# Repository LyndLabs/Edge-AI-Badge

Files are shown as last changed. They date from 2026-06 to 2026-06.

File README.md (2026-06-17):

# Edge AI Foundation Badge

  

The Edge AI Badge lets you plug-and-play with the latest vendor hardware at conference workshops and wirelessly connect with other attendees! Use the badge to explore the Edge AI curriculum, plug into sensors, and start building apps.

- 📄 [Read the docs →](https://lyndlabs.github.io/edge-ai-badge-docs)
- 💻 [Download or contribute to firmware](https://github.com/lyndlabs/edge-ai-badge-firmware).

## Hardware 
The badge is a modular PCB that allows you to customize your own face & backplates - the hardware platform is consistent at future conferences and makes it easy for attendees to design their own add-ons, or vendors that want to contribute hardware. 

It's built around the ESP32-S3, selected for its cryptographic core + secure boot, communication protocols (WiFi, BLE, ESP-NOW), infrared hardware, native USB, and ubiquitous support.

---

## Contents
- **assets**: logos, renders, global design assets
    - *find local assets under subfolders*
- **pcb**: KiCAD design files for `main`, `face`, `back`
- **fab**: production-ready pcb + laser files

## Versions & Notes
Versions bumped per batch release, revisions tracked for minor design changes per board - `main`, `face`, `back` tracked separately.

### v0 - 26/06/08
- Main boards + backplate only - released in green HASL
- Wrong SMD standoff drilling size + CPL in production batch - used regular standoffs
- CPL + BOM discrepancy, released for visibility but pls do not order

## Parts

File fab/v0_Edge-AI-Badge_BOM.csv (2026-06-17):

Reference | Value | DNP | Footprint | Datasheet | LCSC
C1,C40,C41 | 22uF |  | Capacitor_SMD:C_0402_1005Metric |  | C3845593
C2,C12,C18,C37 | 100nF |  | Capacitor_SMD:C_0402_1005Metric |  | C1525
C3,C4,C6,C21 | 0.1uF |  | Capacitor_SMD:C_0402_1005Metric |  | C1525
C5,C17,C19,C24,C25,C33 | 1uF |  | Capacitor_SMD:C_0402_1005Metric |  | C14445,C3845593
C9,C10 | 4.7uF |  | Capacitor_SMD:C_0402_1005Metric |  | C315248
C13,C27 | 10uF |  | Capacitor_SMD:C_0402_1005Metric |  | C315248
C38 | 22pF |  | Capacitor_SMD:C_0402_1005Metric |  | C76960
D1,D3,D4,D6 | D_Schottky |  | Diode_SMD:D_SOD-523 |  | C917006
D10 | PRTR5V0U2X |  | Package_TO_SOT_SMD:SOT-143 | https://assets.nexperia.com/documents/data-sheet/PRTR5V0U2X.pdf | C5180302
D14,D15 | VSMY14940 |  | Temporal:vsmy14940 |  | C511069
H1,H2,H3,H4 | M2 x 1.5mm |  |  |  | C5301775
H5,H6,H7,H8 | M2x6mm |  |  |  | C5301797
J1 | USB C 2.0 |  | Connector_USB:USB_C_Receptacle_Palconn_UTC16-G | https://www.usb.org/sites/default/files/documents/usb_type-c.zip | C2765186
J3 | JST PH |  | Connector_JST:JST_PH_S2B-PH-SM4-TB_1x02-1MP_P2.00mm_Horizontal |  | C295747
J5,J6 | SM04B
L5 | 2.2uh |  | Inductor_SMD:L_Coilcraft_LPS3010 | https://www.lcsc.com/datasheet/lcsc_datasheet_2410121211_YJYCOIN-YHNR4020-2R2M_C2926400.pdf | C2926400
LED1,LED2,LED3,LED4,LED5,LED6,LED7,LED8,LED9,LED10,LED11,LED12 | APA102-2020 |  | LED_SMD:LED-APA102-2020 | http://www.led-color.com/upload/201604/APA102-2020%20SMD%20LED.pdf
M1 | Z3OC1T8219731
Q1,Q3 | DMN2058U |  | Package_TO_SOT_SMD:SOT-23 | http://www.diodes.com/assets/Datasheets/DMN2058U.pdf | C461001
Q2 | MMBT3904 |  | Package_TO_SOT_SMD:SOT-23 | https://www.onsemi.com/pdf/datasheet/pzt3904-d.pdf | C916374
Q4 | BSS138 |  | Package_TO_SOT_SMD:SOT-23 | https://www.onsemi.com/pub/Collateral/BSS138-D.PDF
R1,R2,R3,R4,R5,R12 | 0 |  | Resistor_SMD:R_0201_0603Metric |  | C106228
R6,R16,R18,R21,R26,R28,R29,R30,R31,R32,R38,R45 | 10K |  | Resistor_SMD:R_0402_1005Metric |  | C25767,C60490
R7,R8 | 4.7K |  | Resistor_SMD:R_0402_1005Metric |  | C105871
R9,R10 | 5.1K |  | Resistor_SMD:R_0402_1005Metric |  | C25905
R11,R15,R24 | 150K |  | Resistor_SMD:R_0402_1005Metric |  | C93947
R14 | 680K |  | Resistor_SMD:R_0402_1005Metric |  | C163456
R19,R20 | 1.8K |  | Resistor_SMD:R_0402_1005Metric |  | C203083
R22 | 47K |  | Resistor_SMD:R_0402_1005Metric |  | C163456
R23,R25 | 100K |  | Resistor_SMD:R_0402_1005Metric |  | C60491
R27 | 330 |  | Resistor_SMD:R_0402_1005Metric |  | C112291
R36,R37,R41 | 24 |  | Resistor_SMD:R_0402_1005Metric |  | C270625
R39 | 150 |  | Resistor_SMD:R_0402_1005Metric |  | C138054
R40 | 10 |  | Resistor_SMD:R_0402_1005Metric |  | C138066
SW1 | Reset |  |  |  | C2762971
SW1, SW4,SW5,SW6,SW7,SW8,SW9,SW10,SW11,SW12 | SW_Push |  |  |  | C2762971
U2 | BQ24079RGT |  | Package_DFN_QFN:VQFN-16-1EP_3x3mm_P0.5mm_EP1.6x1.6mm | http://www.ti.com/lit/ds/symlink/bq24079.pdf | C2876751
U3 | ESP32-S3-WROOM-1 |  | RF_Module:ESP32-S3-WROOM-1 | https://www.espressif.com/sites/default/files/documentation/esp32-s3-wroom-1_wroom-1u_datasheet_en.pdf | C2913202
U4 | ST LIS2DH12TR |  | Package_LGA:LGA-12_2x2mm_P0.5mm | https://www.st.com/resource/en/datasheet/lis2DE12.pdf | C110926
U8 | TSOP75338 |  | LyndLabs-Module:TSOP753 |  | C499550
U10 | SY8089 |  | Package_TO_SOT_SMD:SOT-23-5 | https://lcsc.com/product-detail/DC-DC-Converters_Silergy_SY8088AAC_SY8088AAC_C79313.html | C79313
Y1 | 32.768KHz |  | Crystal:Crystal_SMD_3215-2Pin_3.2x1.5mm |  | C97606

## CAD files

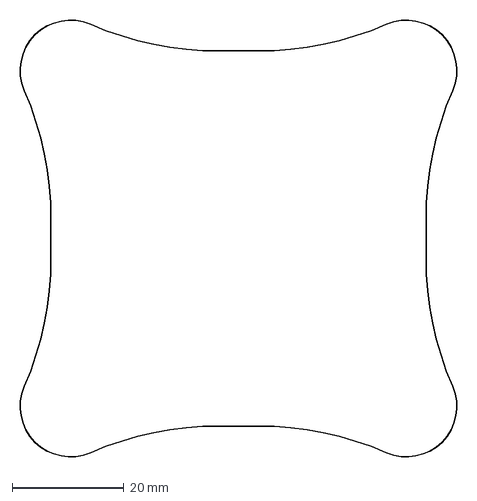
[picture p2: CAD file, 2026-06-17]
assets/outline/v0_Edge-AI-Badge_MAIN-OUTLINE-R1.dxf
79.5 x 79.5 mm

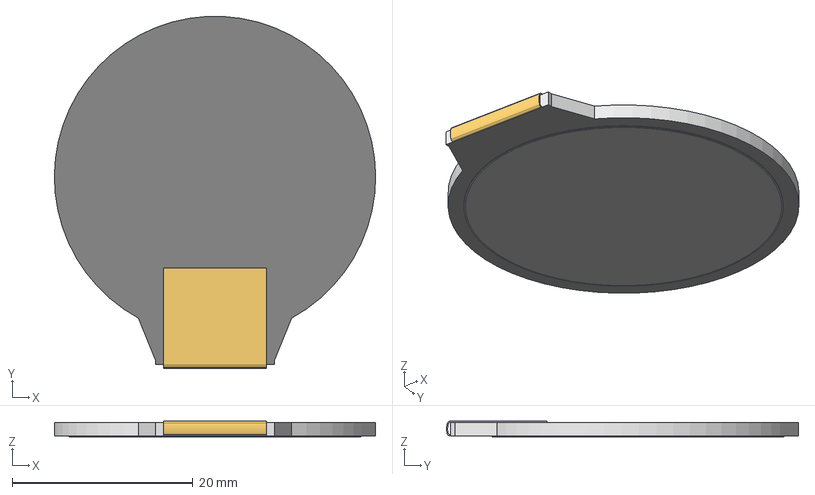
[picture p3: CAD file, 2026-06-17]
assets/models/display.step
35.6 x 39.0 x 1.76 mm
TFT_1.28IN_ROUND_240X240_12P
TFT_1.28IN_ROUND_240X240_12P001
TFT_1.28IN_ROUND_240X240_12P002

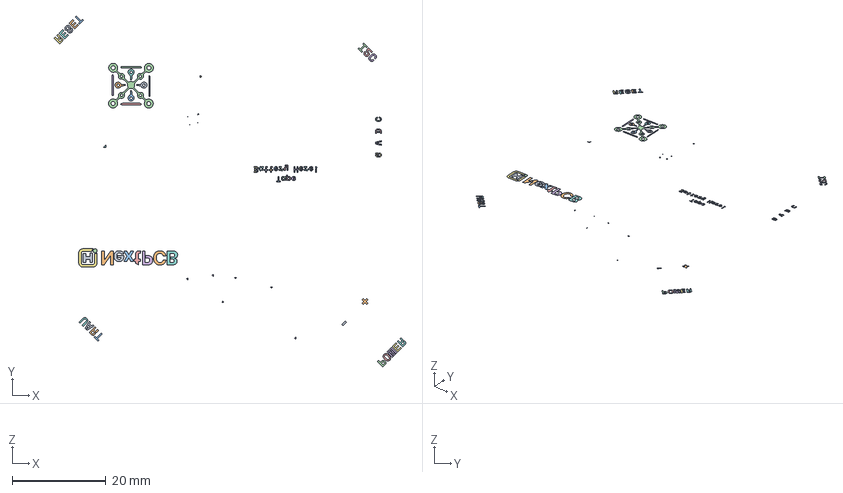
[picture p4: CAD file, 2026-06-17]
assets/outline/V0-Outline.FCStd
75.1 x 75.0 x 0 mm
Path001
Path002
Path003
Path004
Path005
Path006
Path007
Path008
Path009
Path010
Path011
Path012
Path013
Path014
Path015
Path016
Path017
Path018
Path019
Path020
Path021
Path022
Path023
Path024
Path025
Path026
Path027
Path028
Path029
Path030
Path031
Path032
Path033
Path034
Path035
Path036
Path037
Path038
Path039
Path040
Path041
Path042
Path043
Path044
Path045
Path046
Path047
Path048
Path049
Path050
Path068
Path073
Path074
Path075
Path076
Path077
Path078
Path079
Path080
Path081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

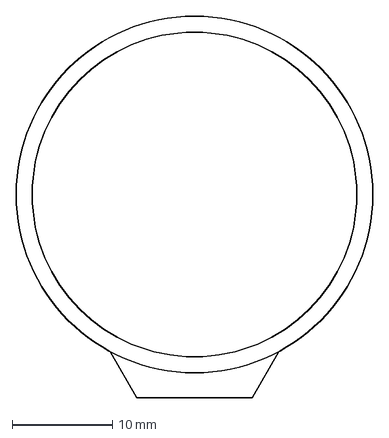
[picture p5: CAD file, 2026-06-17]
assets/Screen-Footprint.dxf
35.6 x 38.1 mm

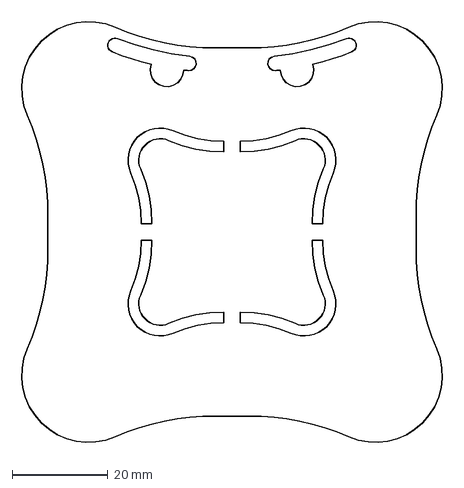
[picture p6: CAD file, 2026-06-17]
assets/outline/v0_Edge-AI-Badge_BACK-OUTLINE-R1.dxf
90.3 x 90.3 mm

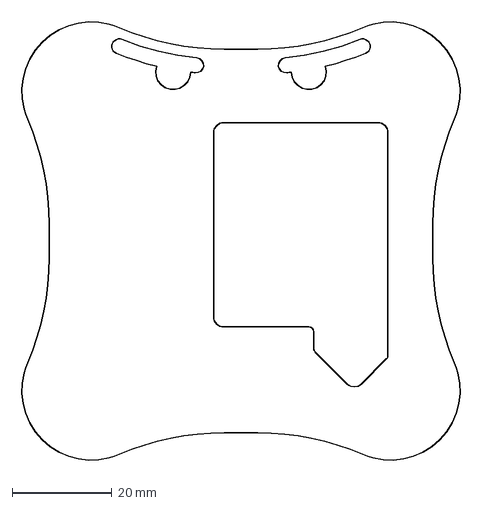
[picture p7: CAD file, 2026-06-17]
assets/outline/v0_Edge-AI-Badge_BACK-OUTLINE-R4.dxf
90.3 x 90.3 mm

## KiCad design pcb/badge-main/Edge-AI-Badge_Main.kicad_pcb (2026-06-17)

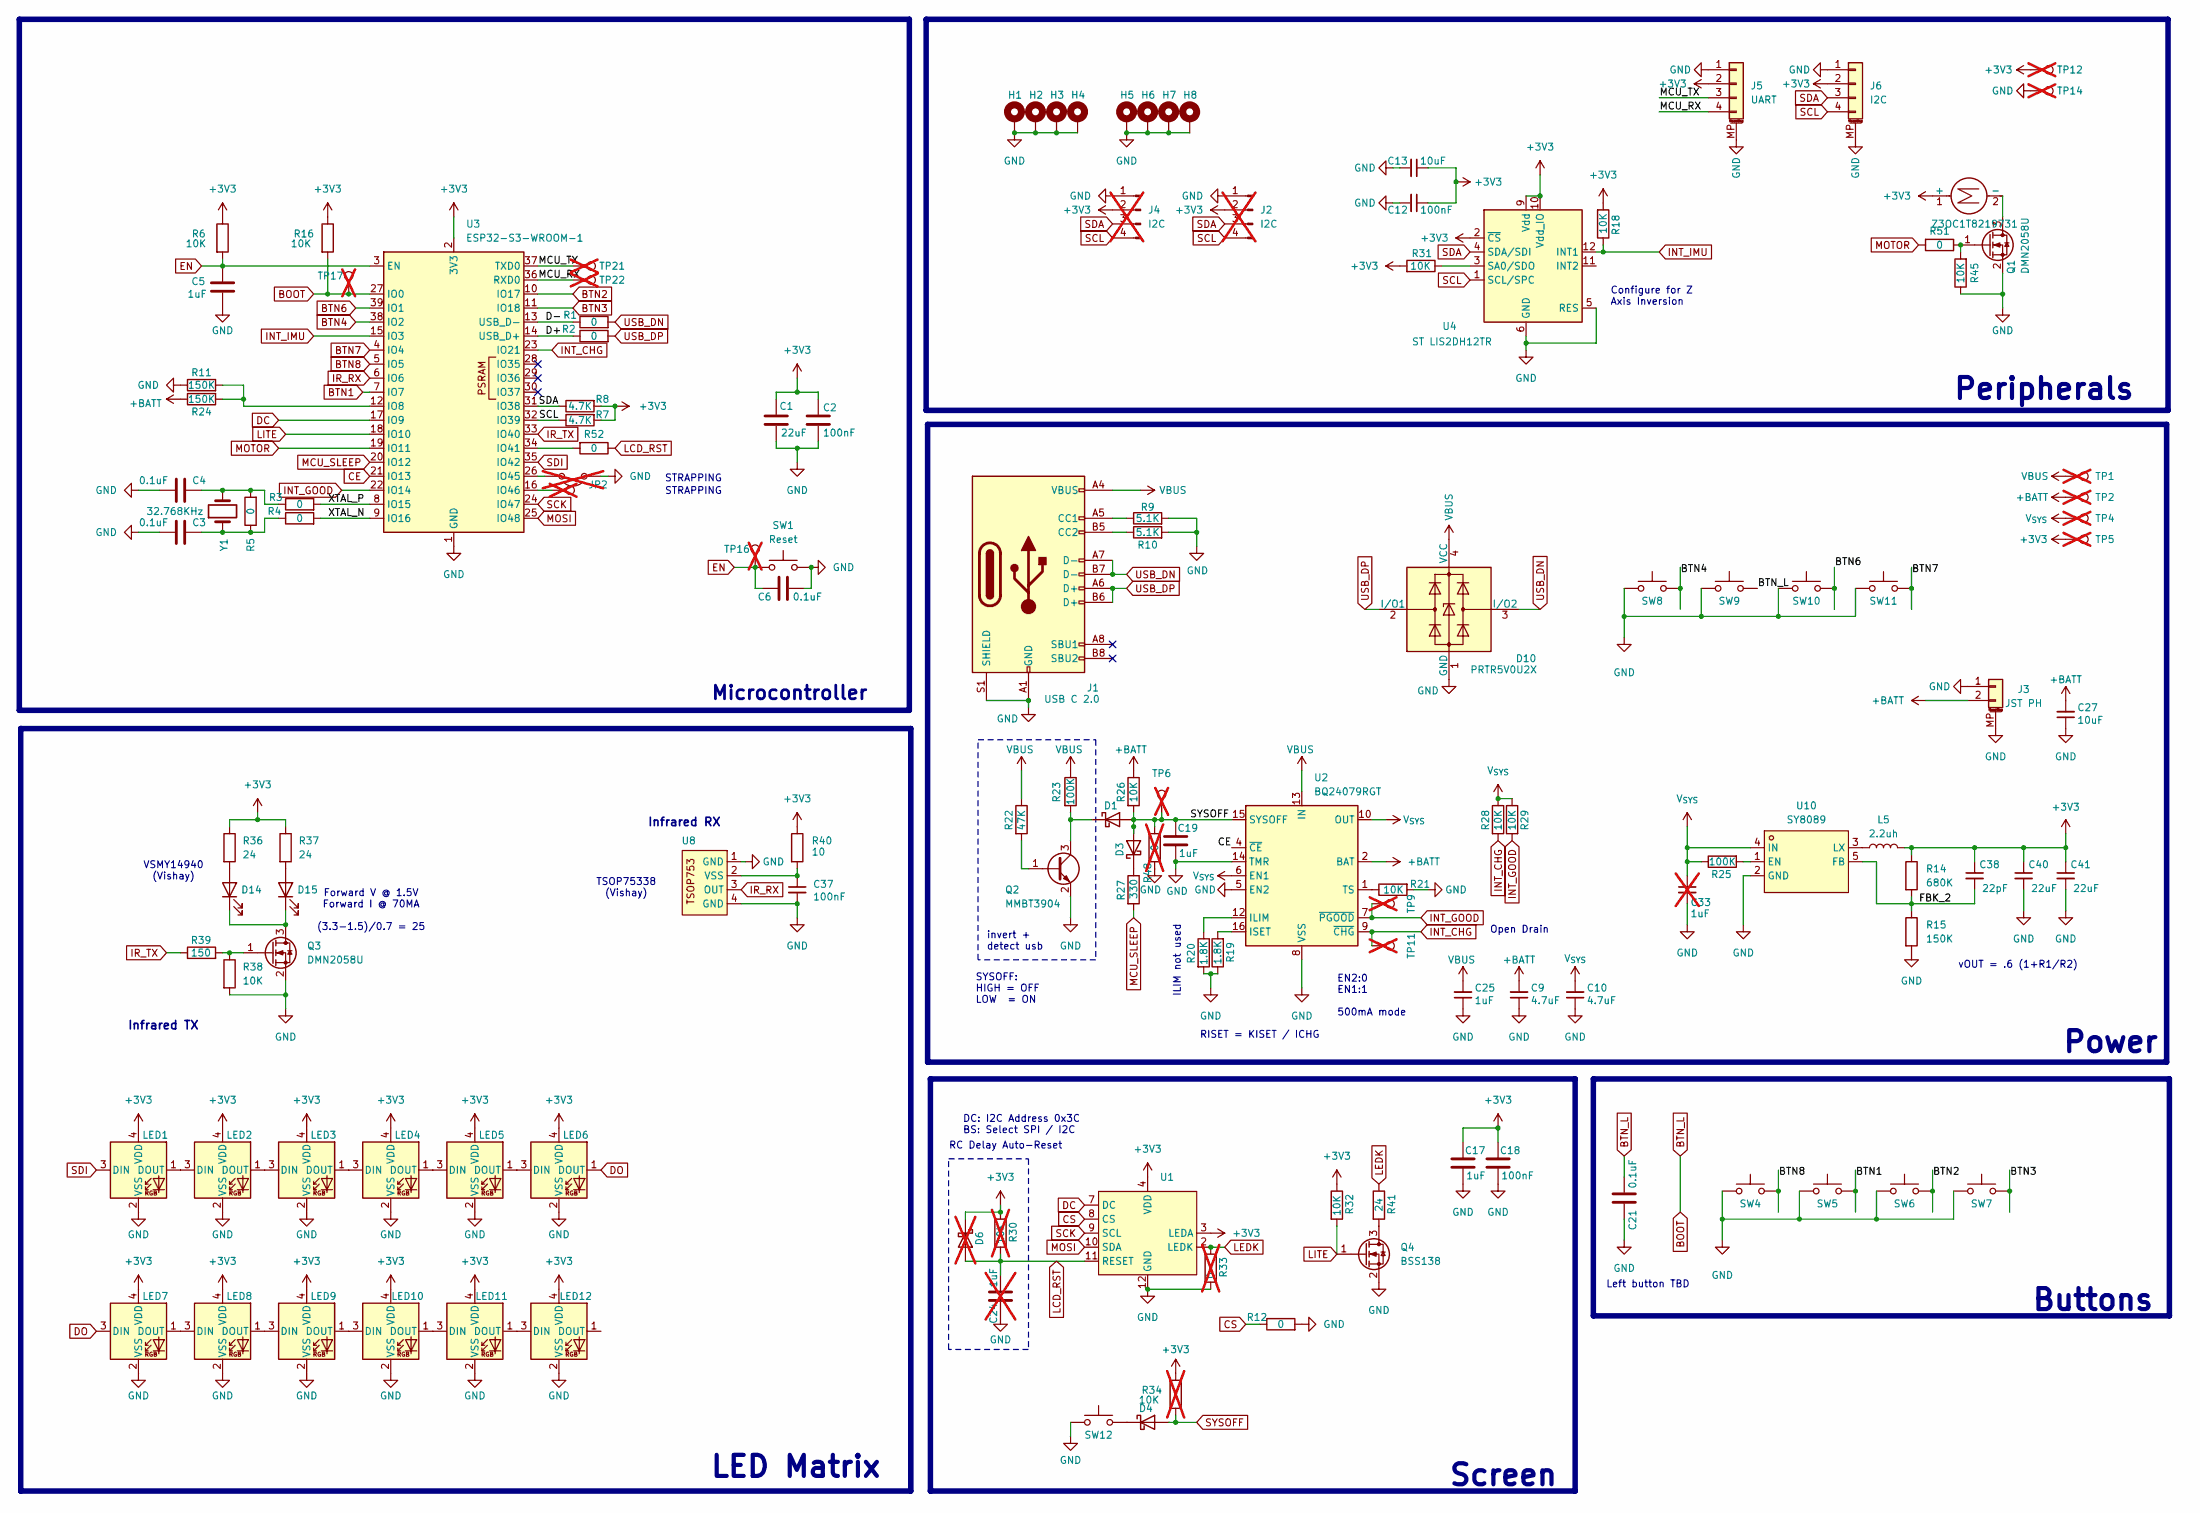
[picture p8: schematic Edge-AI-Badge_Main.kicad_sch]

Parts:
C1, C40, C41: 22uF; C_0402_1005Metric; LCSC C3845593
C2, C12, C18, C37: 100nF; C_0402_1005Metric; LCSC C1525
C3, C4, C6, C21: 0.1uF; C_0402_1005Metric; LCSC C1525
C5, C17, C19, C25: 1uF; C_0402_1005Metric; LCSC C14445
C9, C10: 4.7uF; C_0402_1005Metric; LCSC C315248
C13, C27: 10uF; C_0402_1005Metric; LCSC C315248
C24: 1uF; C_0402_1005Metric; LCSC C14445; not fitted
C33: 1uF; C_0402_1005Metric; LCSC C3845593; not fitted
C38: 22pF; C_0402_1005Metric; LCSC C76960
D1, D3, D4: D_Schottky; D_SOD-523; LCSC C917006
D6: D_Schottky; D_SOD-523; LCSC C917006; not fitted
D10: PRTR5V0U2X; SOT-143; LCSC C5180302
D14, D15: VSMY14940; vsmy14940; LCSC C511069
H1, H2, H3, H4, H5, H6, H7, H8: MountingHole_Pad
J1: USB C 2.0; USB_C_Receptacle_Palconn_UTC16-G; LCSC C2765186
J2, J4: I2C; PinSocket_1x04_P2.54mm_Vertical; not fitted
J3: JST PH; JST_PH_S2B-PH-SM4-TB_1x02-1MP_P2.00mm_Horizontal; LCSC C295747
J5: UART
J6: I2C
JP2: Jumper_2_Open; SolderJumper-2_P1.3mm_Open_RoundedPad1.0x1.5mm; not fitted
L5: 2.2uh; L_Coilcraft_LPS3010; LCSC C2926400
LED1, LED2, LED3, LED4, LED5, LED6, LED7, LED8, LED9, LED10, LED11, LED12: WS2812B-2020; LED_WS2812B-2020_PLCC4_2.0x2.0mm
M1: Z3OC1T8219731
Q1, Q3: DMN2058U; SOT-23; LCSC C461001
Q2: MMBT3904; SOT-23; LCSC C916374
Q4: BSS138; SOT-23
R1, R2, R3, R4, R5, R12: 0; R_0201_0603Metric; LCSC C106228
R6, R16, R18, R21, R31, R32, R38, R45: 10K; R_0402_1005Metric; LCSC C60490
R7, R8: 4.7K; R_0402_1005Metric; LCSC C105871
R9, R10: 5.1K; R_0402_1005Metric; LCSC C25905
R11, R15, R24: 150K; R_0402_1005Metric; LCSC C93947
R14: 680K; R_0402_1005Metric; LCSC C163456
R19, R20: 1.8K; R_0402_1005Metric; LCSC C203083
R22: 47K; R_0402_1005Metric; LCSC C163456
R23, R25: 100K; R_0402_1005Metric; LCSC C60491
R26, R28, R29: 10K; R_0402_1005Metric; LCSC C25767
R27: 330; R_0402_1005Metric; LCSC C112291
R30, R34: 10K; R_0402_1005Metric; LCSC C60490; not fitted
R33: 0; R_0402_1005Metric; LCSC C60490; not fitted
R36, R37, R41: 24; R_0402_1005Metric; LCSC C270625
R39: 150; R_0402_1005Metric; LCSC C138054
R40: 10; R_0402_1005Metric; LCSC C138066
R48: 0; R_0402_1005Metric; LCSC C106228; not fitted
R51, R52: 0; R_0402_1005Metric; LCSC C106228
SW1: Reset; LCSC C231329
SW4, SW5, SW6, SW7, SW8, SW9, SW10, SW11, SW12: SW_Push; LCSC C25168849
TP1, TP2, TP4, TP5, TP6, TP8, TP9, TP11, TP12, TP14, TP16, TP17, TP21, TP22: TestPoint; TestPoint_Pad_D1.0mm; not fitted
U1: GC9A01
U2: BQ24079RGT; VQFN-16-1EP_3x3mm_P0.5mm_EP1.6x1.6mm; LCSC C2876751
U3: ESP32-S3-WROOM-1; LCSC C2913202
U4: ST LIS2DH12TR; LGA-12_2x2mm_P0.5mm; LCSC C110926
U8: TSOP75338; TSOP753; LCSC C499550
U10: SY8089; SOT-23-5; LCSC Part C79313
Y1: 32.768KHz; Crystal_SMD_3215-2Pin_3.2x1.5mm; LCSC C97606

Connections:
+3V3: C1.1, C2.1, C12.1, C13.1, C17.1, C18.1, C38.1, C40.1, C41.1, D6.1 (K), J2.2, J4.2, J5.2, J6.2, L5.2, LED1.4 (VDD), LED2.4 (VDD), LED3.4 (VDD), LED4.4 (VDD), LED5.4 (VDD), LED6.4 (VDD), LED7.4 (VDD), LED8.4 (VDD), LED9.4 (VDD), LED10.4 (VDD), LED11.4 (VDD), LED12.4 (VDD), M1.1 (+), R6.1, R7.2, R8.2, R14.1, R16.1, R18.2, R30.1, R31.2, R32.1, R34.1, R36.1, R37.1, R40.1, TP5.1 (1_1), TP12.1 (1_1), U1.3 (LEDA), U1.4 (VDD), U3.2 (3V3), U4.2 (~CS), U4.9 (Vdd), U4.10 (Vdd_IO)
+BATT: C9.2, C27.2, J3.2, R24.1, R26.1, TP2.1 (1_1), U2.2 (BAT), U2.3 (BAT)
/D+: R2.1, U3.14 (USB_D+)
/D-: R1.1, U3.13 (USB_D-)
/FBK_2: C38.2, R14.2, R15.1, U10.5 (FB)
/MCU_RX: J5.4, TP22.1 (1_1), U3.36 (RXD0)
/MCU_TX: J5.3, TP21.1 (1_1), U3.37 (TXD0)
/XTAL_N: R4.2, U3.9 (IO16)
/XTAL_P: R3.2, U3.8 (IO15)
BOOT: C21.2, R16.2, SW9.2, TP17.1 (1_1), U3.27 (IO0)
BTN1: SW5.2, U3.7 (IO7)
BTN2: SW6.2, U3.10 (IO17)
BTN3: SW7.2, U3.11 (IO18)
BTN4: SW8.2, U3.38 (IO2)
BTN6: SW10.2, U3.39 (IO1)
BTN7: SW11.2, U3.4 (IO4)
BTN8: SW4.2, U3.5 (IO5)
CE: U2.4 (~CE), U3.21 (IO13)
CS: R12.1, U1.8 (CS)
DC: U1.7 (DC), U3.17 (IO9)
DO: LED6.1 (DOUT), LED7.3 (DIN)
EN: C5.1, C6.1, R6.2, SW1.2, TP16.1 (1_1), U3.3 (EN)
GND: C1.2, C2.2, C3.2, C4.2, C5.2, C6.2, C9.1, C10.1, C12.2, C13.2, C17.2, C18.2, C19.2, C21.1, C24.2, C25.1, C27.1, C33.2, C37.2, C40.2, C41.2, D10.1 (GND), H1.1 (1_1), H2.1 (1_1), H3.1 (1_1), H4.1 (1_1), H5.1 (1_1), H6.1 (1_1), H7.1 (1_1), H8.1 (1_1), J1.A1 (GND), J1.A12 (GND), J1.B1 (GND), J1.B12 (GND), J1.S1 (SHIELD), J2.1, J3.1, J3.MP (MountPin), J4.1, J5.1, J5.MP (MountPin), J6.1, J6.MP (MountPin), JP2.2 (B), LED1.2 (VSS), LED2.2 (VSS), LED3.2 (VSS), LED4.2 (VSS), LED5.2 (VSS), LED6.2 (VSS), LED7.2 (VSS), LED8.2 (VSS), LED9.2 (VSS), LED10.2 (VSS), LED11.2 (VSS), LED12.2 (VSS), Q1.2 (S), Q2.2 (E), Q3.2 (S), Q4.2 (S), R9.2, R10.2, R11.1, R12.2, R15.2, R19.1, R20.2, R21.2, R33.2, R38.2, R45.1, R48.1, SW1.1, SW4.1, SW5.1, SW6.1, SW7.1, SW8.1, SW9.1, SW10.1, SW11.1, SW12.1, TP14.1 (1_1), U1.1 (GND), U1.5 (GND), U1.6 (GND), U1.12 (GND), U2.5 (EN2), U2.8 (VSS), U2.14 (TMR), U2.17 (VSS), U3.1 (GND), U3.40 (GND), U3.41 (GND), U4.5 (RES), U4.6 (GND), U4.7 (GND), U4.8 (GND), U8.1 (GND), U8.4 (GND), U10.2 (GND)
INT_CHG: R28.2, TP11.1 (1_1), U2.9 (~CHG), U3.23 (IO21)
INT_GOOD: R29.2, TP9.1 (1_1), U2.7 (~PGOOD), U3.22 (IO14)
INT_IMU: R18.1, U3.15 (IO3), U4.12 (INT1)
IR_RX: U3.6 (IO6), U8.3 (OUT)
IR_TX: R39.1, U3.33 (IO40)
LCD_RST: C24.1, D6.2 (A), R30.2, R52.1, U1.11 (RESET)
LEDK: R33.1, R41.1, U1.2 (LEDK)
LITE: Q4.1 (G), R32.2, U3.18 (IO10)
MCU_SLEEP: R27.2, U3.20 (IO12)
MOSI: U1.10 (SDA), U3.25 (IO48)
MOTOR: R51.2, U3.19 (IO11)
unnamed: C3.1, R4.1, R5.1, Y1.1
unnamed: C4.1, R3.1, R5.2, Y1.2
unnamed: D1.1 (K), Q2.3 (C), R23.2
unnamed: D3.1 (K), R27.1
unnamed: D4.1 (K), SW12.2
unnamed: D14.2 (A), R36.2
unnamed: D14.1 (K), D15.1 (K), Q3.3 (D)
unnamed: D15.2 (A), R37.2
unnamed: J1.A5 (CC1), R9.1
unnamed: J1.B5 (CC2), R10.1
unnamed: JP2.1 (A), U3.26 (IO45)
unnamed: LED1.1 (DOUT), LED2.3 (DIN)
unnamed: LED2.1 (DOUT), LED3.3 (DIN)
unnamed: LED3.1 (DOUT), LED4.3 (DIN)
unnamed: LED4.1 (DOUT), LED5.3 (DIN)
unnamed: LED5.1 (DOUT), LED6.3 (DIN)
unnamed: LED7.1 (DOUT), LED8.3 (DIN)
unnamed: LED8.1 (DOUT), LED9.3 (DIN)
unnamed: LED9.1 (DOUT), LED10.3 (DIN)
unnamed: LED10.1 (DOUT), LED11.3 (DIN)
unnamed: LED11.1 (DOUT), LED12.3 (DIN)
unnamed: M1.2 (-), Q1.3 (D)
unnamed: Q1.1 (G), R45.2, R51.1
unnamed: Q2.1 (B), R22.2
unnamed: Q3.1 (G), R38.1, R39.2
unnamed: Q4.3 (D), R41.2
unnamed: R20.1, U2.12 (ILIM)
unnamed: R19.2, U2.16 (ISET)
unnamed: R21.1, U2.1 (TS)
unnamed: R11.2, R24.2, U3.12 (IO8)
unnamed: R52.2, U3.34 (IO41)
unnamed: TP8.1 (1_1), U3.16 (IO46)
unnamed: R31.1, U4.3 (SA0/SDO)
unnamed: C37.1, R40.2, U8.2 (VSS)
unnamed: R25.2, U10.1 (EN)
unnamed: L5.1, U10.3 (LX)
SCK: U1.9 (SCL), U3.24 (IO47)
SCL: J2.4, J4.4, J6.4, R7.1, U3.32 (IO39), U4.1 (SCL/SPC)
SDA: J2.3, J4.3, J6.3, R8.1, U3.31 (IO38), U4.4 (SDA/SDI)
SDI: LED1.3 (DIN), U3.35 (IO42)
SYSOFF: C19.1, D1.2 (A), D3.2 (A), D4.2 (A), R26.2, R34.2, R48.2, TP6.1 (1_1), U2.15 (SYSOFF)
USB_DN: D10.3 (I/O2), J1.A7 (D-), J1.B7 (D-), R1.2
USB_DP: D10.2 (I/O1), J1.A6 (D+), J1.B6 (D+), R2.2
VBUS: C25.2, D10.4 (VCC), J1.A4 (VBUS), J1.A9 (VBUS), J1.B4 (VBUS), J1.B9 (VBUS), R22.1, R23.1, TP1.1 (1_1), U2.13 (IN)
V_{SYS}: C10.2, C33.1, R25.1, R28.1, R29.1, TP4.1 (1_1), U2.6 (EN1), U2.10 (OUT), U2.11 (OUT), U10.4 (IN)

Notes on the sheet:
Configure for Z Axis Inversion
STRAPPING
VSMY14940 (Vishay)
Buttons
vOUT = .6 (1+R1/R2)
Forward V @ 1.5V Forward I @ 70MA (3.3-1.5)/0.7 = 25
Infrared RX
Microcontroller
RC Delay Auto-Reset
Peripherals
TSOP75338 (Vishay)
LED Matrix
Infrared TX
RISET = KISET / ICHG
DC: I2C Address 0x3C BS: Select SPI / I2C
SYSOFF: HIGH = OFF LOW = ON
Left button TBD
Screen
ILIM not used
Open Drain
Power
EN2:0 EN1:1 500mA mode
invert + detect usb

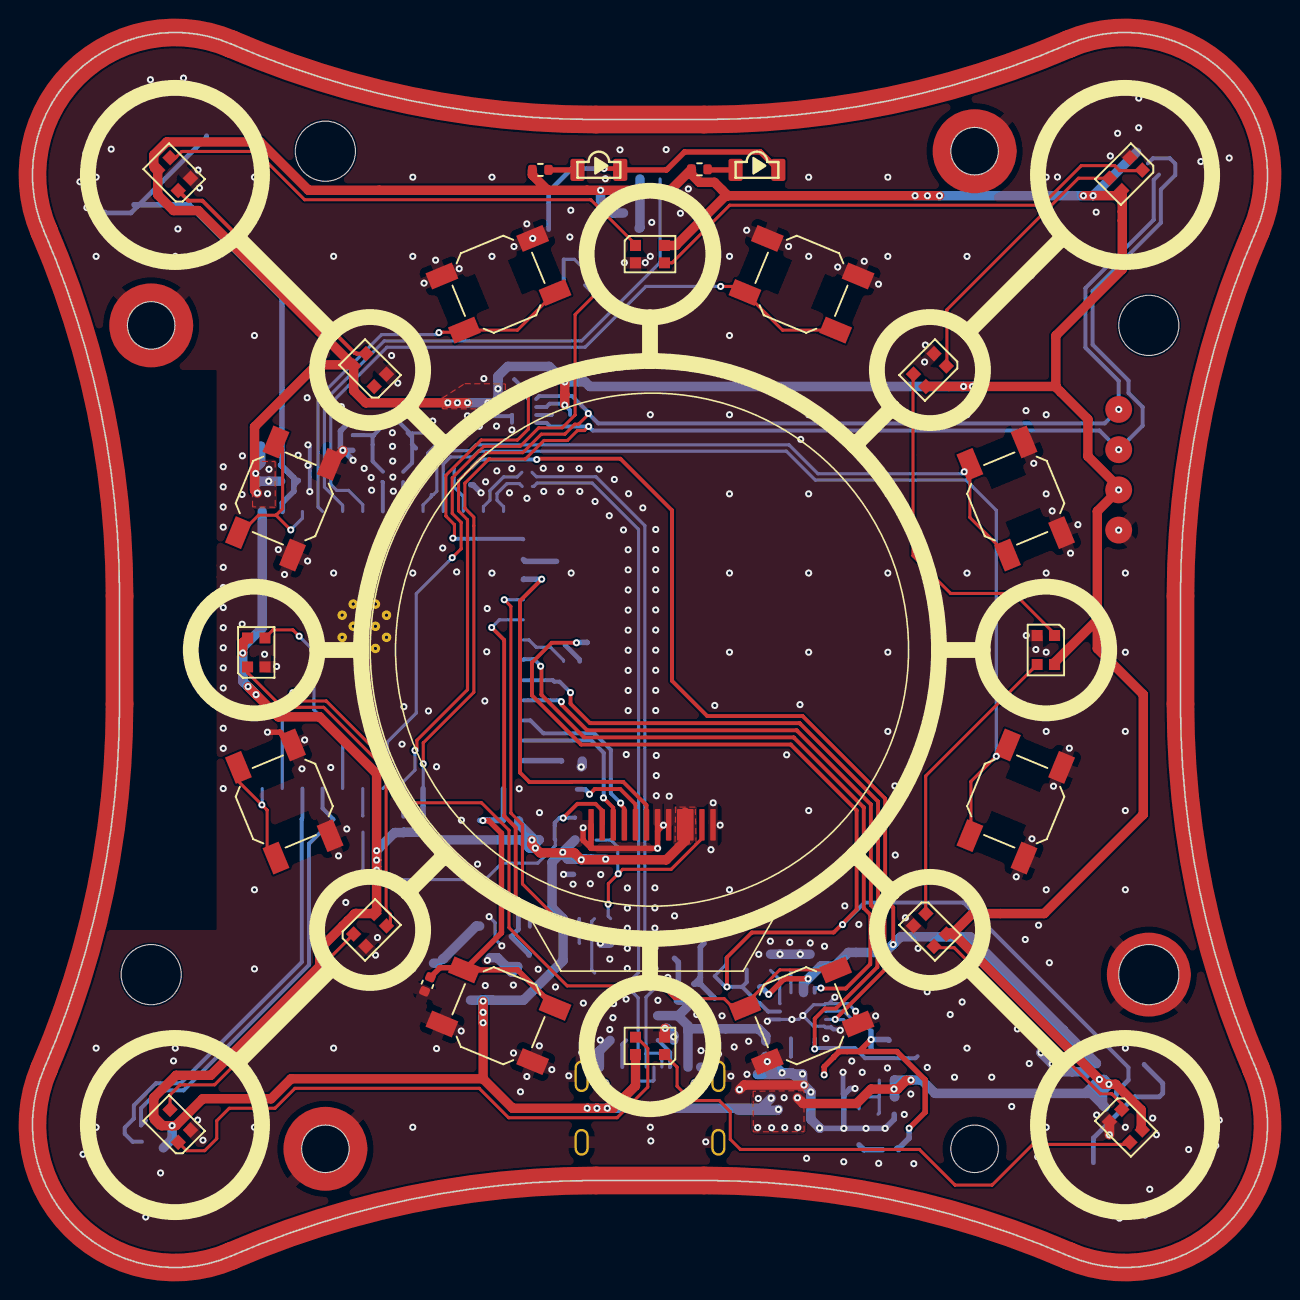
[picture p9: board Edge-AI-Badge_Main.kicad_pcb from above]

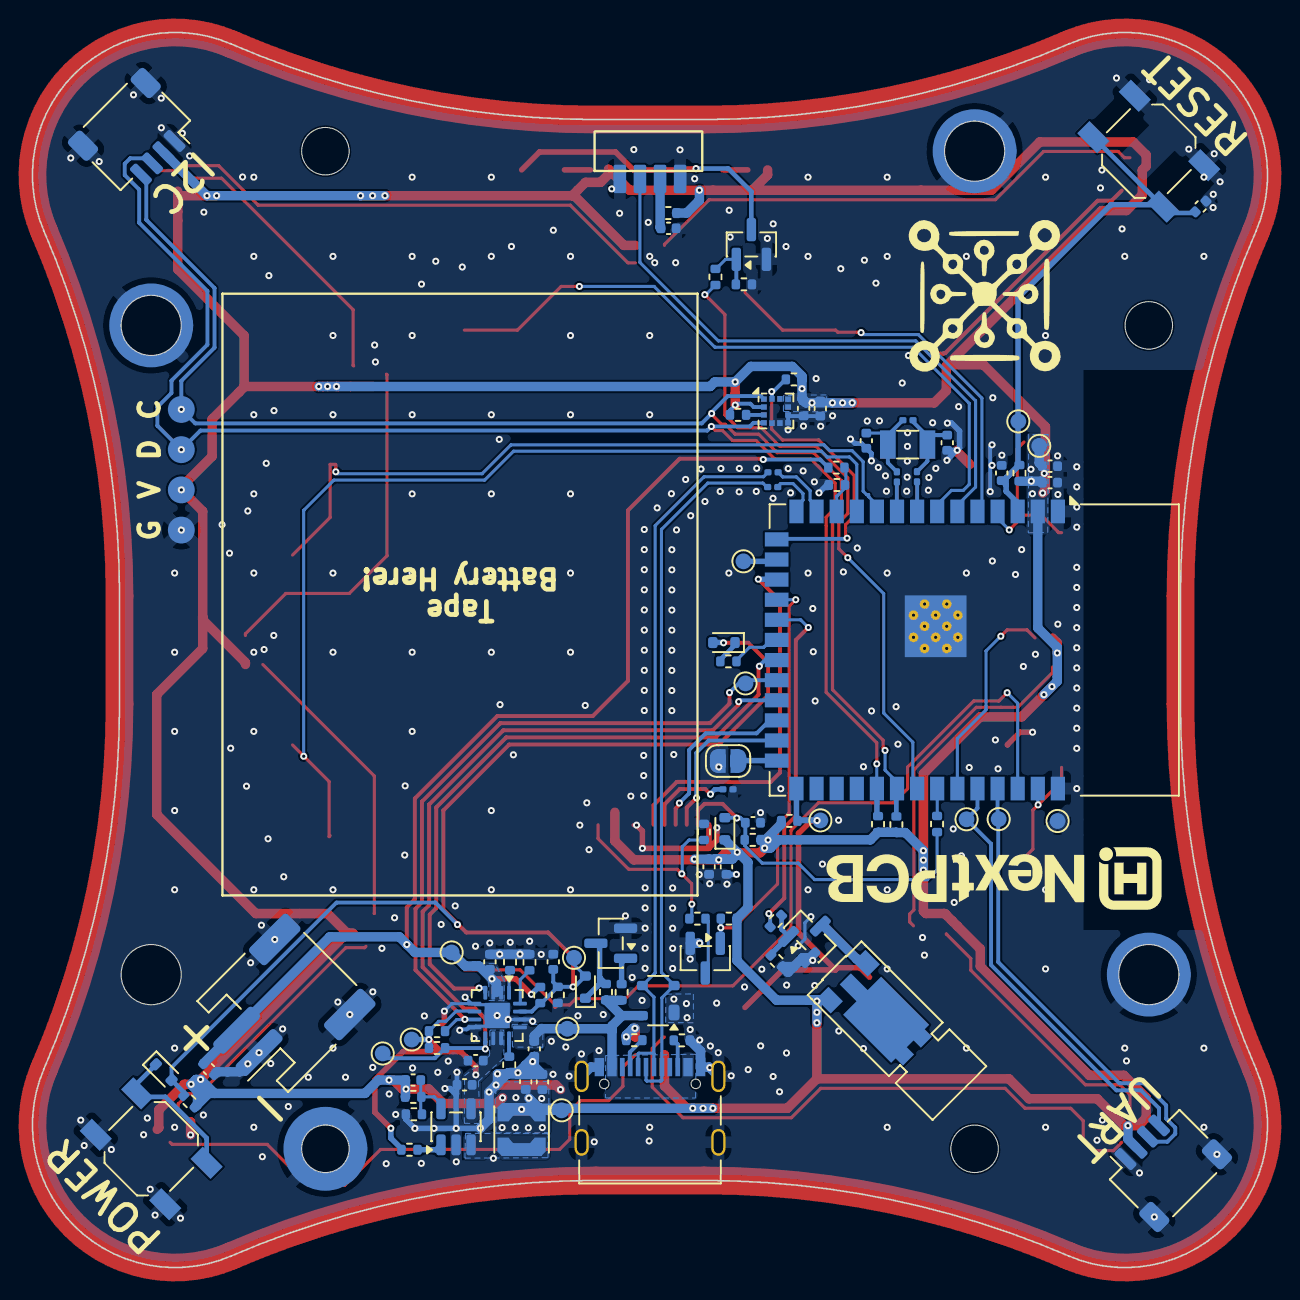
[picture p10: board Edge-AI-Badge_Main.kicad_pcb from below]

Board: 2 copper layers, 78.0 x 78.0 mm, 135 parts (104 on the bottom side), 79 nets.

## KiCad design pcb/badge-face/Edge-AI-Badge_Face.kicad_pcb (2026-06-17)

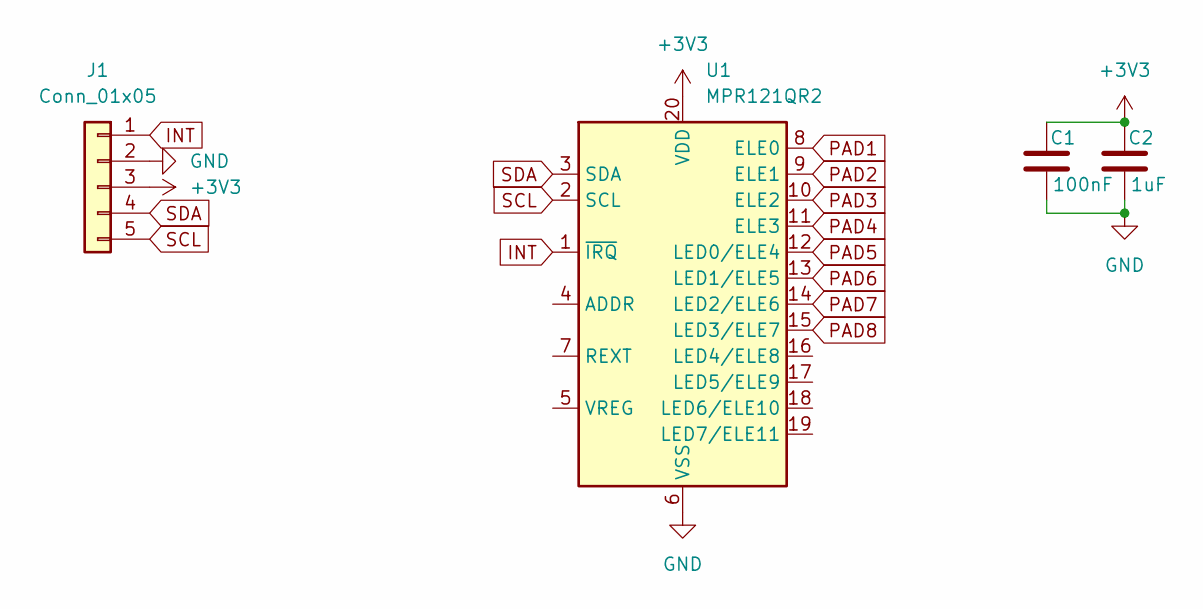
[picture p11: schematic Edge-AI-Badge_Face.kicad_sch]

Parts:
C1: 100nF; C_0402_1005Metric
C2: 1uF; C_0402_1005Metric
J1: Conn_01x05; PinSocket_1x05_P2.54mm_Vertical
U1: MPR121QR2; UQFN-20_3x3mm_P0.4mm

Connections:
+3V3: C1.1, C2.1, J1.3, U1.20 (VDD)
GND: C1.2, C2.2, J1.2, U1.6 (VSS)
INT: J1.1, U1.1 (~IRQ)
PAD1: U1.8 (ELE0)
PAD2: U1.9 (ELE1)
PAD3: U1.10 (ELE2)
PAD4: U1.11 (ELE3)
PAD5: U1.12 (LED0/ELE4)
PAD6: U1.13 (LED1/ELE5)
PAD7: U1.14 (LED2/ELE6)
PAD8: U1.15 (LED3/ELE7)
SCL: J1.5, U1.2 (SCL)
SDA: J1.4, U1.3 (SDA)

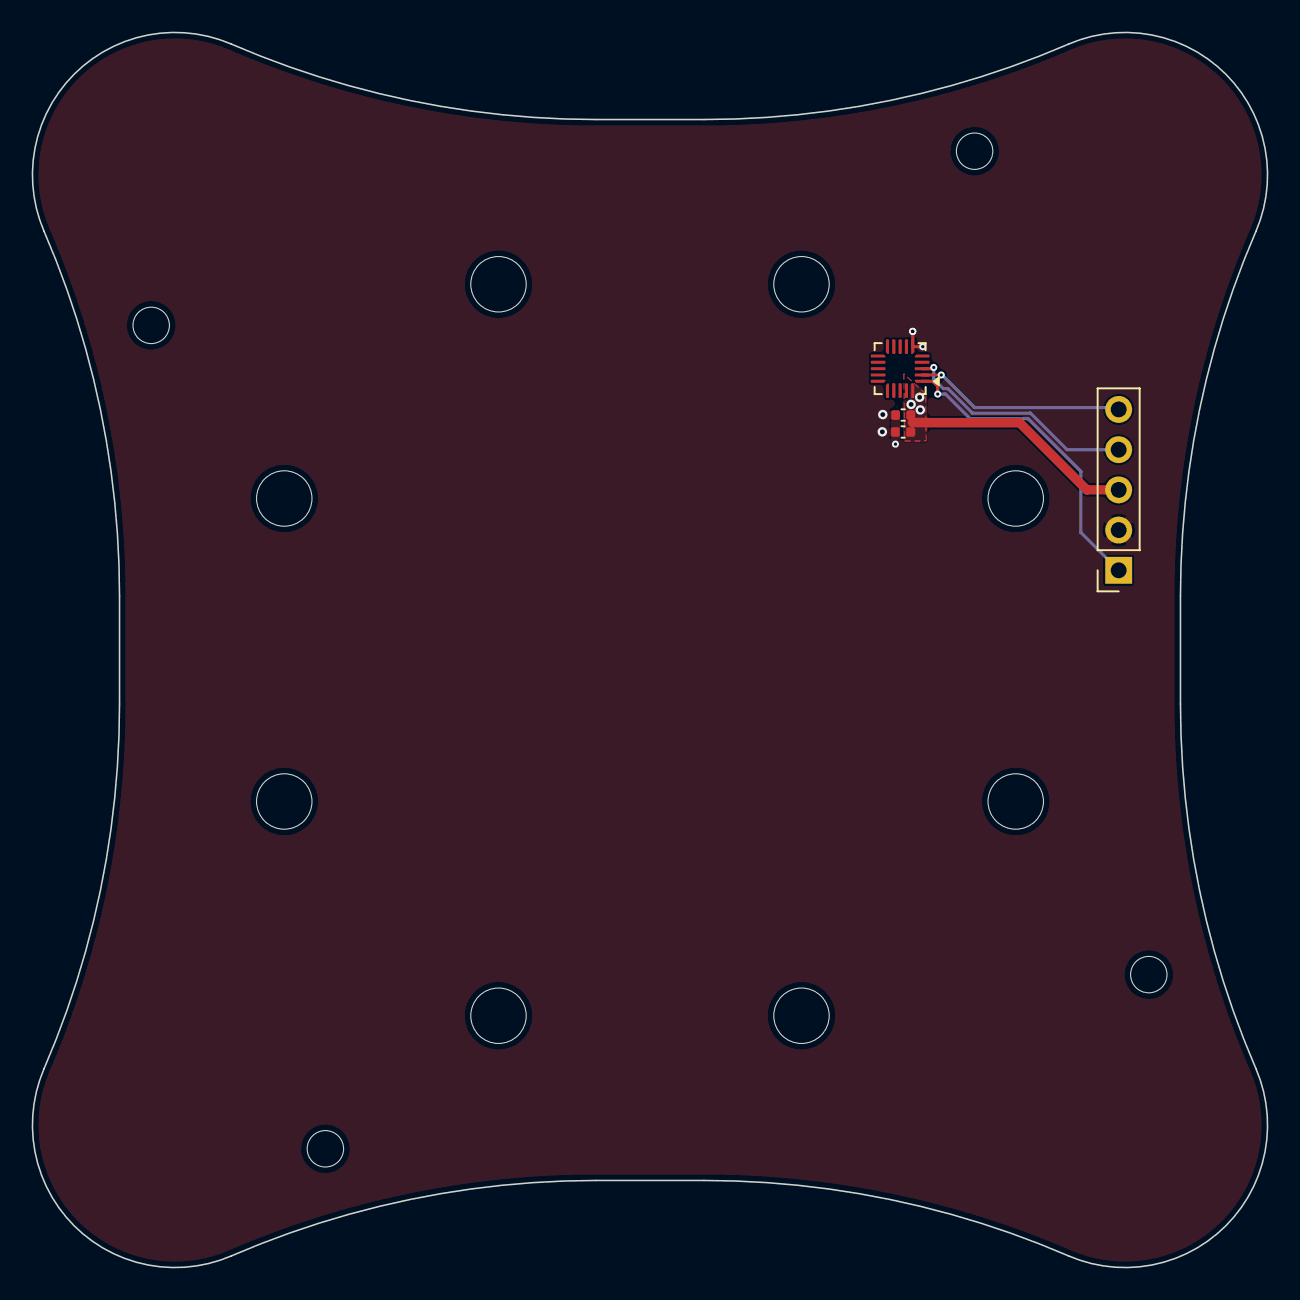
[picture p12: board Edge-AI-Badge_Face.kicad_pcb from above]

Board: 2 copper layers, 78.0 x 78.0 mm, 4 parts (0 on the bottom side), 5 nets.

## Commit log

2026-06-17 push initial v0 design files
    [Edge-AI-Badge_Back.kicad_pcb, Edge-AI-Badge_Back.kicad_sch, Edge-AI-Badge_Face.kicad_pcb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]
2026-06-17 organize some stuff
    [V0-Outline.FCStd, display.step, v0-Edge-AI-Badge_BOM-R0.csv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]
